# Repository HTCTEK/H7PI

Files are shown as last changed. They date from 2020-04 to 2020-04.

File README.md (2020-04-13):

# H7PI

## 量产版本历史
[v0.2](https://gitee.com/htctek/H7PI/tree/bf5159e9c3666d05ed6d5055ce2db61eb0288070) 特点：带8bits LCD接口    
[v1.0](https://gitee.com/htctek/H7PI/tree/e8b1aa18095ffa30b805f85c88335dfa602a2d0a) 特点：除了SD卡座，QSPI Flash引脚，SPI flash/psram引脚外，引出所有引脚，使用type-c接口，取消8bits LCD接口。

## 使用说明 / User Manual
中文：[使用说明](https://pinno.cc)

## 获取一个H7PI / Buy One
淘宝：[购买链接 / shop](https://item.taobao.com/item.htm?spm=a230r.1.14.18.71f35247DnH8yH&id=606908438435&ns=1&abbucket=14#detail)

## Platform
* [H7PI_Arduino](https://github.com/htctek/H7PI_Arduino) is for users who are used to develop arduino
* [H7PI_Samples](https://github.com/htctek/H7PI_Samples) is for users who are used to develop with MDK Keil, but also give an entry for arduino and support freeRTOS.

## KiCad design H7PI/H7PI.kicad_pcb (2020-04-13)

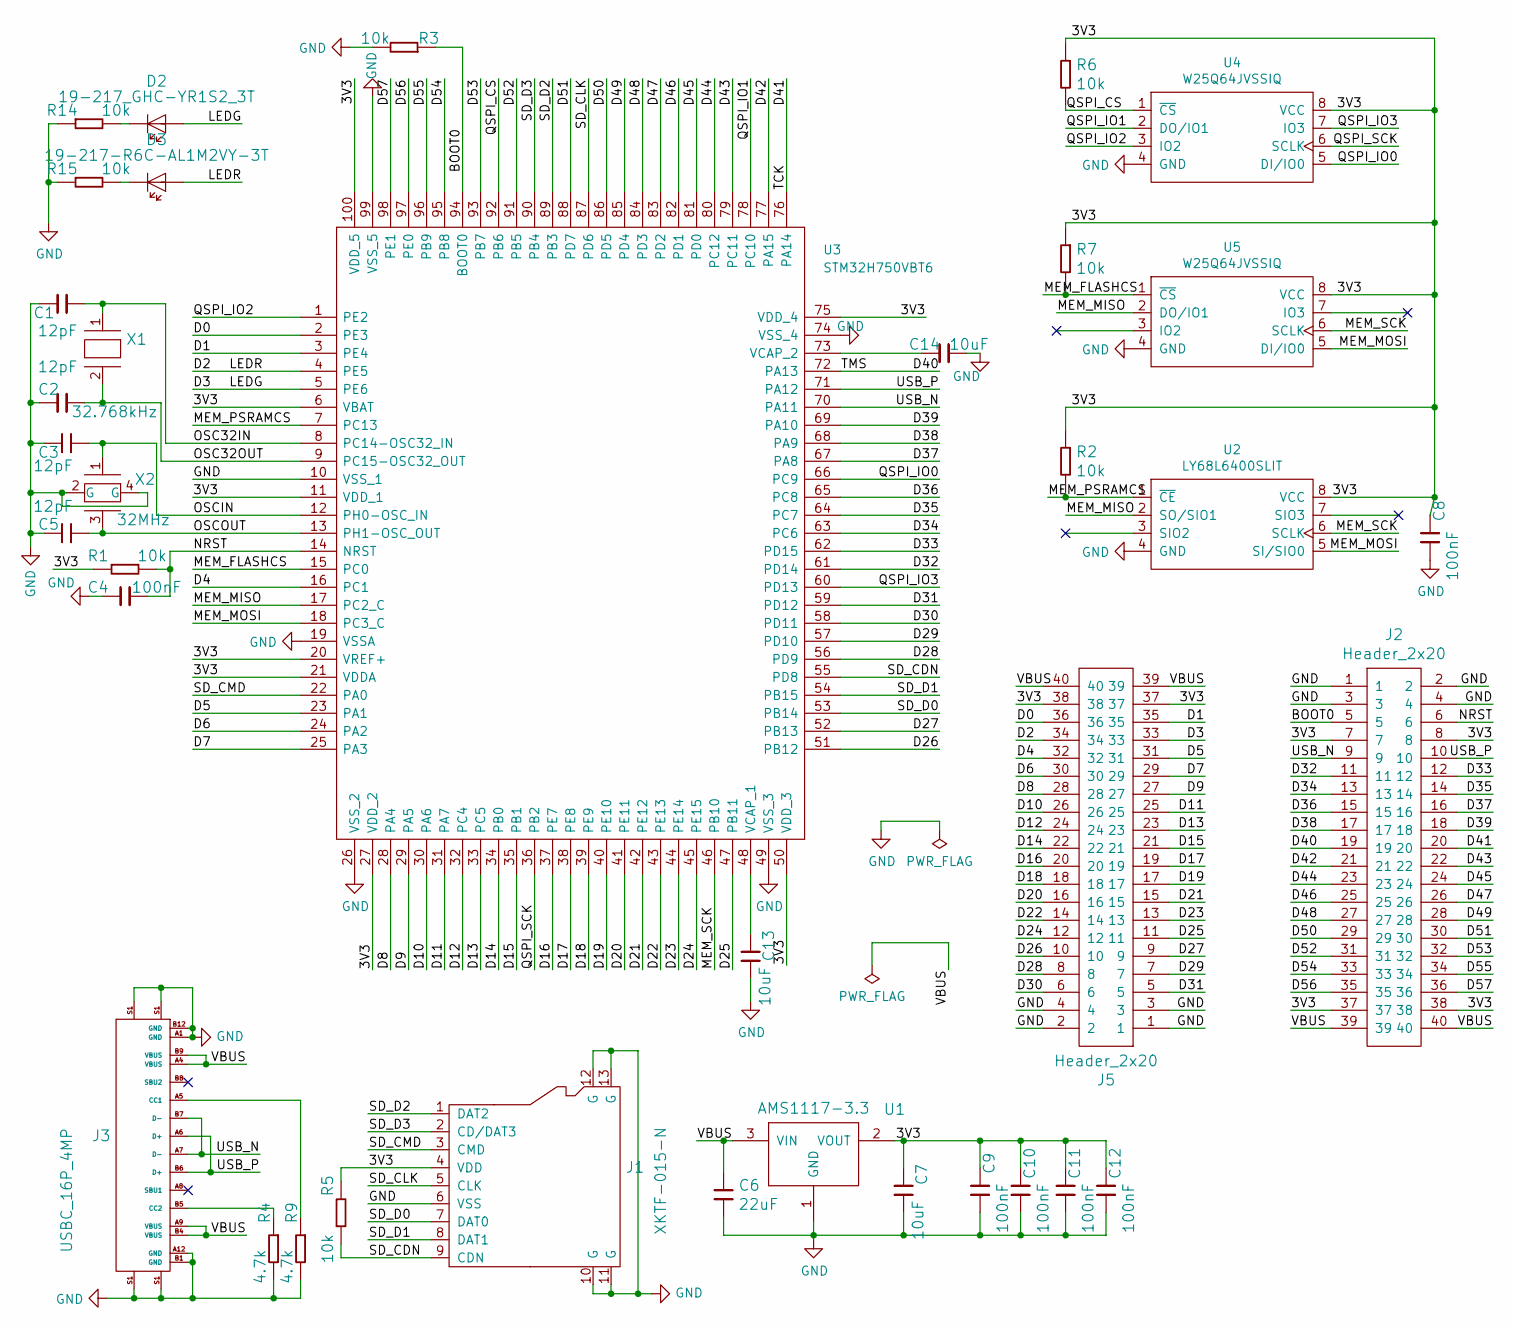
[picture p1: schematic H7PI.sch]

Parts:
C1, C2, C3, C5: 12pF; C_0402_1005Metric; PartNumber 0402CG120J500NT
C4, C8, C9, C10, C11, C12: 100nF; C_0402_1005Metric; PartNumber 0402B104K500NT
C6: 22uF; C_0805_2012Metric; PartNumber CL21A226MAQNNNE
C7, C13, C14: 10uF; C_0402_1005Metric; PartNumber 0402X106M6R3NT
D2: 19-217_GHC-YR1S2_3T; LED_0603_1608Metric; PartNumber 19-217/GHC-YR1S2/3T
D3: 19-217-R6C-AL1M2VY-3T; LED_0603_1608Metric; PartNumber 19-217/R6C-AL1M2VY/3T
J1: XKTF-015-N; Connector_MicroSD_TF_XKB_XKTF-015-N_14.75x17.5mm; PartNumber XKTF-015-N
J2, J5: Header_2x20; PinHeader_2x20_P2.54mm_Vertical
J3: USBC_16P_4MP; USB_C_Receptacle_Palconn_UTC16-G; PartNumber TYPE C连接器USB3.1系列母座端单排16P贴板有柱-5A大电流新ES
R1, R2, R3, R5, R6, R7, R14, R15: 10k; R_0402_1005Metric; PartNumber 0402WGF1002TCE
R4, R9: 4.7k; R_0402_1005Metric; PartNumber 0402WGF4701TCE
U1: AMS1117-3.3; SOT-223; PartNumber AMS1117-3.3
U2: LY68L6400SLIT; SOIC-8_3.9x4.9mm_P1.27mm; PartNumber LY68L6400SLIT
U3: STM32H750VBT6; LQFP-100_14x14mm_P0.5mm; PartNumber STM32H750VBT6
U4, U5: W25Q64JVSSIQ; SOIC-8_5.23x5.23mm_P1.27mm; PartNumber W25Q64JVSSIQ
X1: 32.768kHz; Crystal_SMD_EuroQuartz_EQ161-2Pin_3.2x1.5mm; PartNumber SMD31327681252090
X2: 32MHz; Crystal_SMD_2520-4Pin_2.5x2.0mm; PartNumber S2232000082060

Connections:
/3V3: C7.1, C8.2, C9.2, C10.2, C11.2, C12.2, J1.4 (VDD), J2.7, J2.8, J2.37, J2.38, J5.37, J5.38, R1.1, R2.1, R5.2, R6.1, R7.1, U1.2 (VOUT), U2.8 (VCC), U3.6 (VBAT), U3.11 (VDD_1), U3.20 (VREF+), U3.21 (VDDA), U3.27 (VDD_2), U3.50 (VDD_3), U3.75 (VDD_4), U3.100 (VDD_5), U4.8 (VCC), U5.8 (VCC)
/BOOT0: J2.5, R3.1, U3.94 (BOOT0)
/D0: J5.36, U3.2 (PE3)
/D1: J5.35, U3.3 (PE4)
/D2: D3.2, J5.34, U3.4 (PE5)
/D3: D2.2, J5.33, U3.5 (PE6)
/D4: J5.32, U3.16 (PC1)
/D5: J5.31, U3.23 (PA1)
/D6: J5.30, U3.24 (PA2)
/D7: J5.29, U3.25 (PA3)
/D8: J5.28, U3.28 (PA4)
/D9: J5.27, U3.29 (PA5)
/D10: J5.26, U3.30 (PA6)
/D11: J5.25, U3.31 (PA7)
/D12: J5.24, U3.32 (PC4)
/D13: J5.23, U3.33 (PC5)
/D14: J5.22, U3.34 (PB0)
/D15: J5.21, U3.35 (PB1)
/D16: J5.20, U3.37 (PE7)
/D17: J5.19, U3.38 (PE8)
/D18: J5.18, U3.39 (PE9)
/D19: J5.17, U3.40 (PE10)
/D20: J5.16, U3.41 (PE11)
/D21: J5.15, U3.42 (PE12)
/D22: J5.14, U3.43 (PE13)
/D23: J5.13, U3.44 (PE14)
/D24: J5.12, U3.45 (PE15)
/D25: J5.11, U3.47 (PB11)
/D26: J5.10, U3.51 (PB12)
/D27: J5.9, U3.52 (PB13)
/D28: J5.8, U3.56 (PD9)
/D29: J5.7, U3.57 (PD10)
/D30: J5.6, U3.58 (PD11)
/D31: J5.5, U3.59 (PD12)
/D32: J2.11, U3.61 (PD14)
/D33: J2.12, U3.62 (PD15)
/D34: J2.13, U3.63 (PC6)
/D35: J2.14, U3.64 (PC7)
/D36: J2.15, U3.65 (PC8)
/D37: J2.16, U3.67 (PA8)
/D38: J2.17, U3.68 (PA9)
/D39: J2.18, U3.69 (PA10)
/D40: J2.19, U3.72 (PA13)
/D41: J2.20, U3.76 (PA14)
/D42: J2.21, U3.77 (PA15)
/D43: J2.22, U3.79 (PC11)
/D44: J2.23, U3.80 (PC12)
/D45: J2.24, U3.81 (PD0)
/D46: J2.25, U3.82 (PD1)
/D47: J2.26, U3.83 (PD2)
/D48: J2.27, U3.84 (PD3)
/D49: J2.28, U3.85 (PD4)
/D50: J2.29, U3.86 (PD5)
/D51: J2.30, U3.88 (PD7)
/D52: J2.31, U3.91 (PB5)
/D53: J2.32, U3.93 (PB7)
/D54: J2.33, U3.95 (PB8)
/D55: J2.34, U3.96 (PB9)
/D56: J2.35, U3.97 (PE0)
/D57: J2.36, U3.98 (PE1)
/MEM_FLASHCS: R7.2, U3.15 (PC0), U5.1 (~CS)
/MEM_MISO: U2.2 (SO/SIO1), U3.17 (PC2_C), U5.2 (DO/IO1)
/MEM_MOSI: U2.5 (SI/SIO0), U3.18 (PC3_C), U5.5 (DI/IO0)
/MEM_PSRAMCS: R2.2, U2.1 (~CE), U3.7 (PC13)
/MEM_SCK: U2.6 (SCLK), U3.46 (PB10), U5.6 (SCLK)
/NRST: C4.1, J2.6, R1.2, U3.14 (NRST)
/OSC32IN: C1.2, U3.8 (PC14-OSC32_IN), X1.1
/OSC32OUT: C2.2, U3.9 (PC15-OSC32_OUT), X1.2
/OSCIN: C3.2, U3.12 (PH0-OSC_IN), X2.1
/OSCOUT: C5.2, U3.13 (PH1-OSC_OUT), X2.3
/QSPI_CS: R6.2, U3.92 (PB6), U4.1 (~CS)
/QSPI_IO0: U3.66 (PC9), U4.5 (DI/IO0)
/QSPI_IO1: U3.78 (PC10), U4.2 (DO/IO1)
/QSPI_IO2: U3.1 (PE2), U4.3 (IO2)
/QSPI_IO3: U3.60 (PD13), U4.7 (IO3)
/QSPI_SCK: U3.36 (PB2), U4.6 (SCLK)
/SD_CDN: J1.9 (CDN), R5.1, U3.55 (PD8)
/SD_CLK: J1.5 (CLK), U3.87 (PD6)
/SD_CMD: J1.3 (CMD), U3.22 (PA0)
/SD_D0: J1.7 (DAT0), U3.53 (PB14)
/SD_D1: J1.8 (DAT1), U3.54 (PB15)
/SD_D2: J1.1 (DAT2), U3.89 (PB3)
/SD_D3: J1.2 (CD/DAT3), U3.90 (PB4)
/USB_N: J2.9, J3.A7 (D-), J3.B7 (D-), U3.70 (PA11)
/USB_P: J2.10, J3.A6 (D+), J3.B6 (D+), U3.71 (PA12)
/VBUS: C6.1, J2.39, J2.40, J3.A4 (VBUS), J3.A9 (VBUS), J3.B4 (VBUS), J3.B9 (VBUS), J5.39, J5.40, U1.3 (VIN)
GND: C1.1, C2.1, C3.1, C4.2, C5.1, C6.2, C7.2, C8.1, C9.1, C10.1, C11.1, C12.1, C13.2, C14.2, J1.6 (VSS), J1.10 (G), J1.11 (G), J1.12 (G), J1.13 (G), J2.1, J2.2, J2.3, J2.4, J3.A1 (GND), J3.A12 (GND), J3.B1 (GND), J3.B12 (GND), J3.S1, J5.1, J5.2, J5.3, J5.4, R3.2, R4.2, R9.2, R14.1, R15.1, U1.1 (GND), U2.4 (GND), U3.10 (VSS_1), U3.19 (VSSA), U3.26 (VSS_2), U3.49 (VSS_3), U3.74 (VSS_4), U3.99 (VSS_5), U4.4 (GND), U5.4 (GND), X2.2 (G), X2.4 (G)
unnamed: C13.1, U3.48 (VCAP_1)
unnamed: C14.1, U3.73 (VCAP_2)
unnamed: D2.1, R14.2
unnamed: D3.1, R15.2
unnamed: J3.A5 (CC1), R9.1
unnamed: J3.B5 (CC2), R4.1

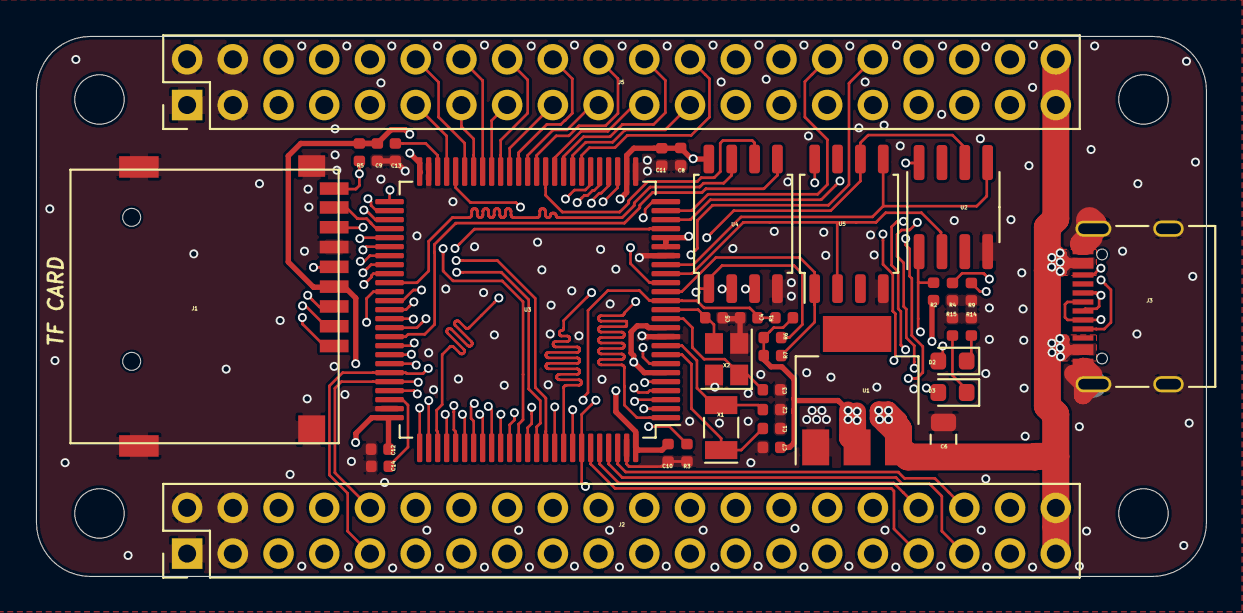
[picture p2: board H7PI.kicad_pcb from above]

Board: 4 copper layers, 65.0 x 30.0 mm, 37 parts (0 on the bottom side), 93 nets.

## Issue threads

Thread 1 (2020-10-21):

H7PI_Exp_MultiMedia电路板建议

Ghazigq, 2020-10-21:
1.摄像头及phy芯片直接使用晶振，去除单片机上的DCMI_MCLK、ETH_MCLK引脚
2.spi屏幕的LEDA与LEDK极性颠倒
3.PHY：ETH_RXER未使用，可移除
4.摄像头：SCL SDA建议更换引脚，因占用了串口引脚
5.DCMI：DCMI_PWND未使用，可移除
6.建议更换PHY芯片

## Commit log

2019-10-29 0.2版本，经试产可用于量产
    [H7PI.kicad_pcb, H7PI.sch]
2019-12-24 更新了图纸的信息
    [H7PI.sch]
2019-12-24 更新readme，增加中文简要说明
2019-12-24 增加英文首页readme add english readme
2019-12-28 v0.3 1. 增加电压支持到12V 2. 增加双USB口通信（不能同时用） 3. 增加USB通孔，用于底板扩展，正常为DNP状态
    [H7PI.kicad_pcb, H7PI.sch]
2020-01-10 update readme and pic
    [H7PI.kicad_pcb, H7PI.sch]
2020-01-16 v0.4 add pin info to bottom silk change pin name to Dx,Ax.
    [H7PI.kicad_pcb, H7PI.sch]
2020-03-20 v1.0开发起点 1. 不再使用树莓派外型 2. 使用Type C USB接口 3. 不再板载LCD接口 4. 板载PSRAM,QSPI FLASH,SPI FLASH 5. 保留TF卡接口
    [H7PI.kicad_pcb, H7PI.sch]
2020-03-20 v1.0第一次推送，待打样 Signed-off-by: fuhua-chen <fuhua-chen@outlook.com>
    [H7PI.kicad_pcb, H7PI.sch]
2020-04-13 更新晶振配置 Signed-off-by: fuhua.chen <fuhua-chen@outlook.com>
    [H7PI.kicad_pcb, H7PI.sch]
